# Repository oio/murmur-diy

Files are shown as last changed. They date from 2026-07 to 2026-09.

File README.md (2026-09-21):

# A mur mur's guide to the galaxy

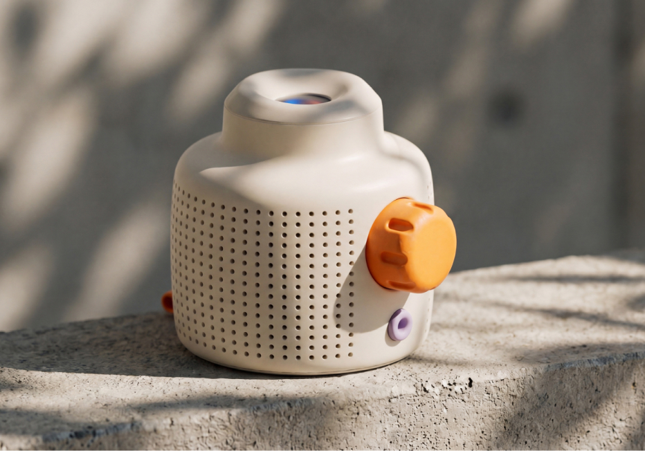
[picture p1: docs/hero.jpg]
mur mur


[mur mur](https://www.murmur.living/) is a small speaker with a world inside.
Not a playlist or a stream, but a living soundscape you can listen to or peek into.

An experiment by [oio](https://oio.studio) and [Mattering](https://matteringstudio.com).

## The DIY version

This guide helps you build the open source hardware prototype of mur mur using readily available off-the-shelf parts. It comes loaded with pre-generated soundscapes for you to enjoy. You can build it with the full feature set (display, battery, charging, and audio) or skip some features for a display-only object. 

Questions while building? Join the oio Discord below:



#### Steps of this guide:

[1 · Order & print parts](#1-order-and-print-parts)

[2 · Upload code](#2-upload-code)

[3 · Assembly](#3-assembly)

[4 · How to use](#4-how-to-use)

## ❶ Order and print parts

First we need to order a bunch of stuff. The complete bill of materials is right below. The diagram shows you where things go. Filaments are sorted by the type of mur mur and print files need to be printed with the different filaments.

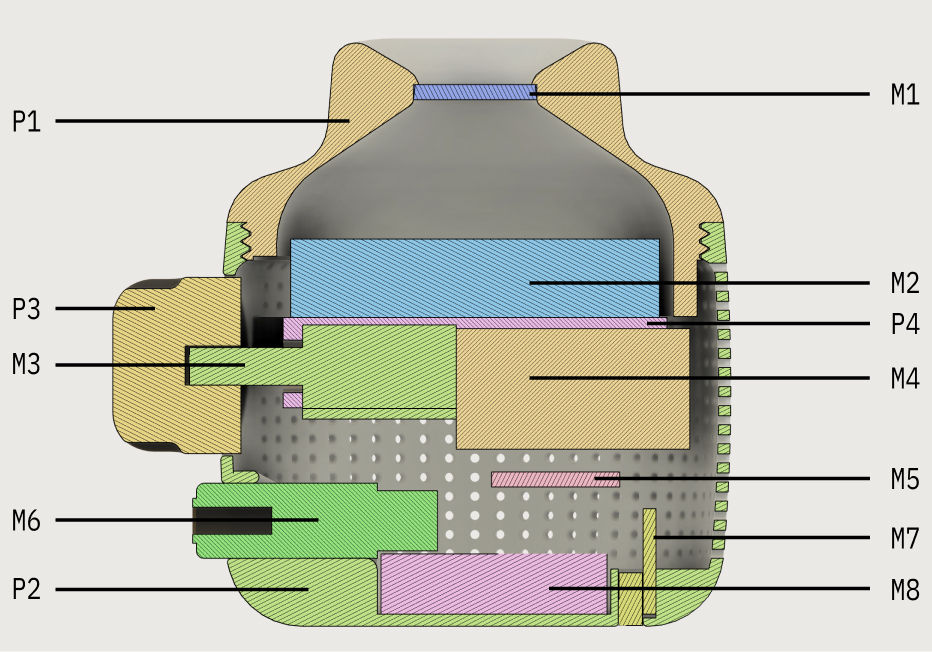
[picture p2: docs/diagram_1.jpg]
BOM diagram


#### BOM

| ID  | Name | Link |
| --- | --- | --- |
| M1  | Lens 16mm (20mm FL) | [Amazon](https://www.amazon.nl/dp/B0G3PH9RPP) |
| M2  | Display Module (ESP32-S3-Touch-AMOLED-1.75, 466×466) | [Waveshare](https://www.waveshare.com/esp32-s3-touch-amoled-1.75.htm) |
| M3  | Amplifier (PAM8403 with potentiometer) | [Amazon](https://www.amazon.nl/dp/B09VT68PHX) |
| M4  | Speaker 3 watt 4 ohm / 2 watt 8 ohm | [Amazon](https://www.amazon.nl/dp/B0DB1WM4QR) |
| M5  | DAC (PCM5102A) | [Amazon](https://www.amazon.nl/dp/B0F7LL4S8Z) |
| M6  | Headphone jack (3.5 mm extension) | [Amazon](https://www.amazon.nl/dp/B0GHQFPSLJ) |
| M7  | Battery charger (TP4057 USB-C) | [Amazon](https://www.amazon.nl/dp/B0F59VQ8JC) |
| M8  | Battery | [Amazon](https://www.amazon.nl/dp/B0F88S2V1Y) |
| M9  | M2 screws | Any 4-6mm M2 bolt |
| M10 | Micro SD | Any MicroSD card (at least 4GB) |
| M11 | Male Pin Header (2.54mm) | Any 2.54mm male header |

> **Note:** Most shopping links point to Amazon Netherlands. The same parts (or close equivalents) are widely available across Europe and the US, use the product names and specs here as a search reference, then order from a local seller if that’s easier.

#### Filament

> **Note:** The filaments listed below are just examples of the exact ones we used for our prototypes. Feel free to use any 3D printing filament (PLA, PETG, etc.) and color combination you like!

| Color | Block | Plot | Pond |
| --- | --- | --- | --- |
| Primary | [Link](https://www.3djake.nl/esun/pla-matte-light-khaki) | [Link](https://www.3djake.nl/esun/pla-matte-matcha-green) | [Link](https://www.3djake.nl/polymaker/polyterra-pla-dual-glacier-blue-ice-blue) |
| Secondary | [Link](https://www.3djake.nl/esun/pla-matte-tangerine) | [Link](https://www.3djake.nl/polymaker/polyterra-pla-dual-camouflage-dark-green-brown) | [Link](https://www.3djake.nl/formfutura/tough-pla-dark-blue?sai=9932) |

#### 3D print files

Print the four parts below before you assemble. Match filament to your mur mur type (Block, Plot, or Pond) from the table above, primary for the shells, secondary for the dial and mount.

| ID  | Name | Color | Link |
| --- | --- | --- | --- |
| P1  | Top shell | Primary | [murmur_top_shell.stl](prints/murmur_top_shell.stl) |
| P2  | Bottom shell | Primary | [murmur_buttom_shell.stl](prints/murmur_buttom_shell.stl) |
| P4  | Mount | Secondary | [murmur_mount.stl](prints/murmur_mount.stl) |

Use supports on the shells (especially overhangs around the openings), and print one part at a time for cleaner surfaces. The mount (P4) holds the display and speaker. Once the parts are printed and the electronics ordered, flash the firmware, then come back here for wiring and assembly.

## ❷ Upload code

Plug in the board via USB-C. One-time setup:

```bash
brew install arduino-cli
arduino-cli core update-index && arduino-cli core install esp32:esp32
arduino-cli lib install JPEGDEC
arduino-cli lib install "GFX Library for Arduino"
```

Flash the firmware:

```bash
cd firmware && ./flash.sh
```

Hold **BOOT** while plugging in USB if the port does not appear. See `[firmware/README.md](firmware/README.md)` for details.

Put your `.avi` files on a FAT32 microSD card (root), insert it, then power on. The video loops on the round 466×466 AMOLED.

> **Battery:** the 1.75 module has onboard AXP2101 charging (MX1.25 battery header). The separate TP4057 charger (M8) is optional if you prefer an external charge board.

## ❸ Assembly

For the assembly you need just a few things:

- 3D printer
- Computer
- Soldering iron
- Wire stripper
- Screwdriver (for M2 screws)
- Double-sided tape

First step is to wire up all the components. Follow the schematic diagram to solder or connect all wires in the right ways. We used male headers and female jumper wires on some parts to make it easier.

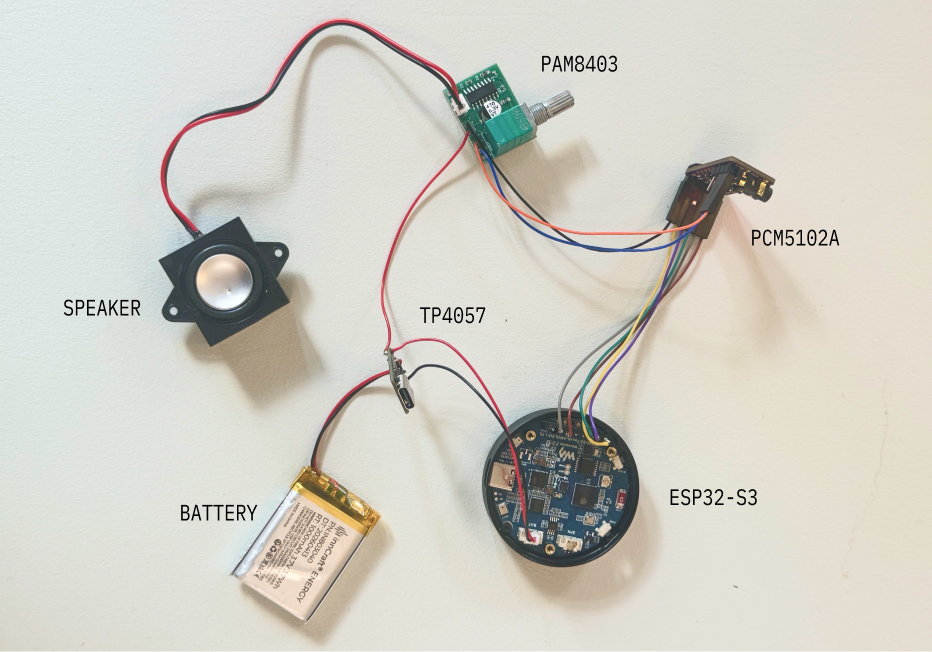
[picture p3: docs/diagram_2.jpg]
Wiring diagram


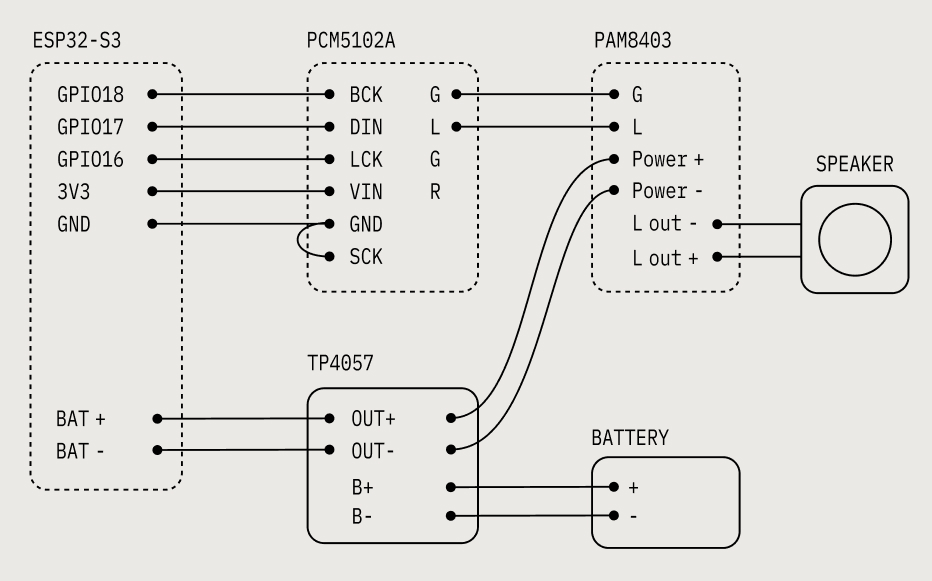
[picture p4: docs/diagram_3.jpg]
Schematic


The diagram above is the pin-level wiring map.

**ESP32-S3 → PCM5102A (I2S):** **GPIO18 → BCK**, **GPIO17 → DIN**, **GPIO16 → LCK**, **3V3 → VIN**, **GND → GND**. Also tie DAC **SCK to GND**.

**PCM5102A → PAM8403 (analog):** **G → G** and **L → L**. Do not swap those two.

**Power:** run **both** PAM8403 **Power +** and **Power −** from the TP4057 (**OUT+** / **OUT−**). Do not take amp power from the ESP 3V3 rail, and do not use the DAC analog ground as the amp’s power ground. The TP4057 also feeds the battery (**B+** / **B−**) and the board’s **BAT +** / **BAT −** connector.

Power the wired stack and confirm video and audio before you close anything up. When that works, put the parts together in the shell.

#### Putting the parts together

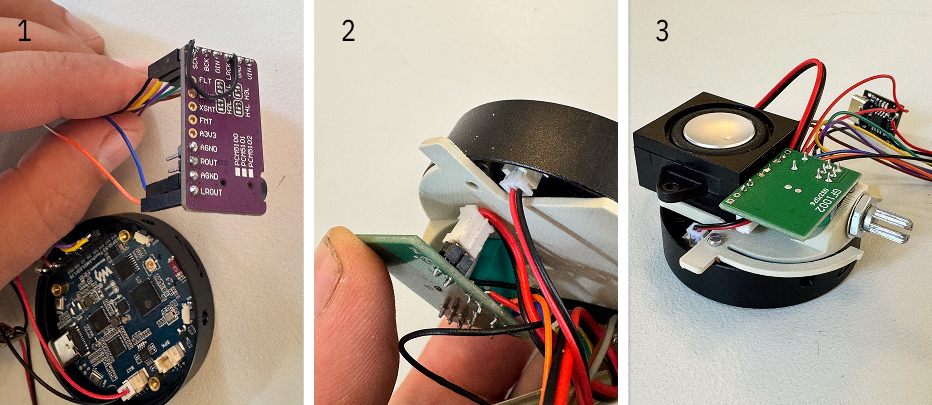
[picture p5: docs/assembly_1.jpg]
Assembly Step 1


1. Add an 8-pin male header to the ESP pinout. Then solder some female jumper cables to GPIO18, 17, 16, 3V3, and GND and connect them to the PCM5102A. Make sure to wire the SCK to GND. See photo as an example.
2. Wire up the audio output from the PCM5102A to the audio input on the PAM8403: **G to G**, **L to L**. Connect PAM8403 **Power +** and **Power −** directly to the TP4057 **OUT+** and **OUT−**.
3. Insert and fasten the PAM8403 to the 3D-printed mounting plate.

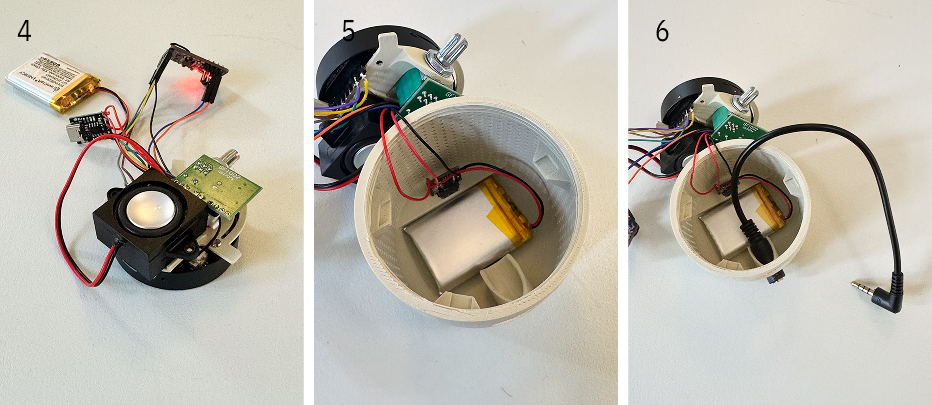
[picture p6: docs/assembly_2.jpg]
Assembly Step 2


4. You should have everything wired up, and it should look something like this. Now is a good time to test the screen and audio. Insert the SD card with the media files and flash the firmware.
5. Insert the battery at the bottom with some double-sided tape, and insert the TP4057 into its dedicated slot.
6. Insert the audio jack cable, doubling as the battery locking system.

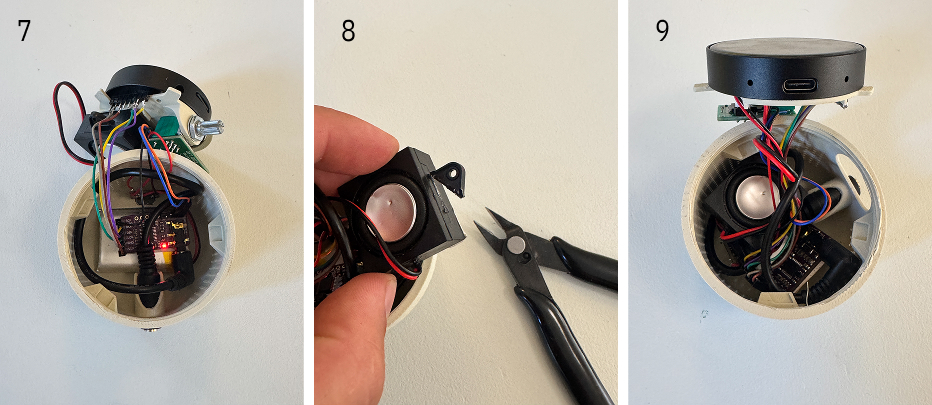
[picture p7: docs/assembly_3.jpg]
Assembly Step 3


7. From here on, we will attempt to fit in all the electronics (this may get tight, depending on the amount of wires and thicknesses). Carefully place the PCM5102A on or next to the battery.
8. It can help to snap off the speaker tabs.
9. Everything should fit inside, leaving clearance above the 3 mounting studs.

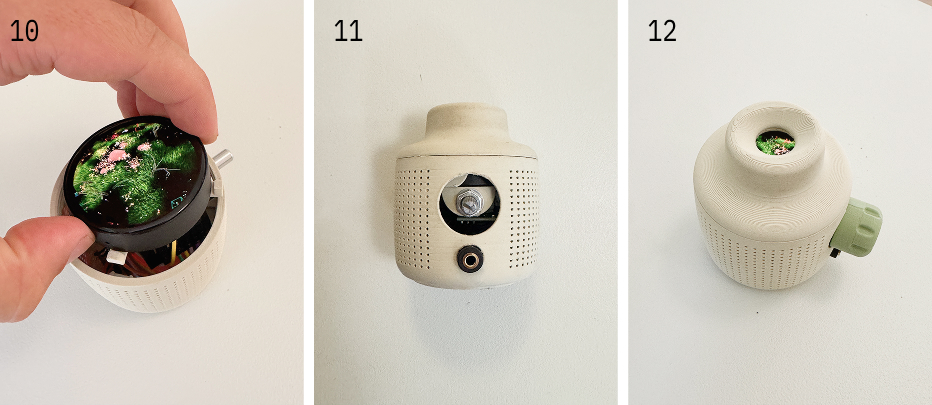
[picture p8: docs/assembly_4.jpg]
Assembly Step 4


10. Insert the display by aligning the mounting pins to the mounting studs.
11. Screw on the top shell with the lens installed. Make sure to rotate the top until the inner opening is revealed (see photo). You may need to clean the 3D-printed edge for a good fit. When fully installed, this will lock the mount and display firmly in place.
12. Plug in the 3D-printed dial, and you should be done. 

## ❹ How to use

Make sure a microSD card with your generated media files (e.g., `city.avi`, `forrest.avi`, `water.avi`) on the root is inserted, then power on. The video loops on the round display with sound through the speaker or headphone jack. Give the device a solid shake to switch between themes!

| Control | Action |
| --- | --- |
| Volume | **Turn** the potentiometer / 3D-printed dial. |
| Shake | **Switch Theme** — changes the current theme (e.g. from city to forest to water). |
| Turn On / Off | **Option 1:** Plug in the charging cable at the bottom.<br>**Option 2:** Insert a needle or wire in the top right 2nd hole.<br>**Option 3:** Unscrew the top shell and click the button manually.|

---

## License

This project is licensed under the [Creative Commons Attribution-NonCommercial-NoDerivatives 4.0 International (CC BY-NC-ND 4.0) License](LICENSE).

---

Stuck on wiring, flashing, or assembly? Hop into the [oio Discord](https://oio.studio/discord) and ask, we are happy to help.



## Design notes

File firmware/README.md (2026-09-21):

# VideoPlayer firmware

Looping MJPEG player for the Waveshare **ESP32-S3-Touch-AMOLED-1.75** (466×466 CO5300 AMOLED).

## Flash from the command line

**Requirements:** USB-C data cable, board plugged in.

**One-time setup:**

```bash
brew install arduino-cli
arduino-cli core update-index
arduino-cli core install esp32:esp32
arduino-cli lib install JPEGDEC
arduino-cli lib install "GFX Library for Arduino"
```

**Flash** (from this folder):

```bash
./flash.sh
```

If the port is not detected, hold **BOOT**, plug in USB, release **BOOT**, then run again.

If several serial ports show up (common on Windows), set the port for one flash:

```bash
PORT=COM3 ./flash.sh
```

Press **RESET** after upload. Insert the SD card (`video.avi` on the root) and connect the speaker.

---

## Hardware Required

| Part | Notes |
|---|---|
| ESP32-S3-Touch-AMOLED-1.75 | Waveshare 466×466 AMOLED module |
| TF / micro-SD card | FAT32, any capacity ≤32 GB |
| Speaker | Plug into the MX1.25 speaker connector |
| USB-C cable | Data-capable (for flashing) |

Battery connects to the onboard MX1.25 lithium header (AXP2101 charging) — no external TP4057 needed.

---

## 1 – Prepare Your Video

```bash
./scripts/convert_for_sd.sh YOUR_INPUT.mp4
```

Or manually:

```bash
ffmpeg -i YOUR_INPUT.mp4 \
  -vf "scale=466:466:force_original_aspect_ratio=decrease,pad=466:466:(ow-iw)/2:(oh-ih)/2,setsar=1" \
  -r 15 \
  -vcodec mjpeg -q:v 8 \
  -af "highpass=f=150,alimiter=limit=-3dB" \
  -acodec pcm_s16le -ar 22050 -ac 1 \
  video.avi
```

Copy `video.avi` to the **root** of the TF card.

---

## Board settings

| Setting | Value |
|---|---|
| Board | `ESP32S3 Dev Module` |
| USB CDC On Boot | `Enabled` |
| Flash Size | `16MB` |
| Partition Scheme | `16M Flash (3MB APP/9.9MB FATFS)` |
| PSRAM | `OPI PSRAM` |
| CPU Frequency | `240MHz` |

---

## Files

```
firmware/
├── firmware.ino             Main sketch
├── AVI_Player.h/.cpp        MJPEG AVI parser + I2S → PCM5102A
├── Display_CO5300.h/.cpp    CO5300 QSPI AMOLED (Arduino_GFX)
├── SD_Card.h/.cpp           TF card (SPI: CLK2/CMD1/D03/CS41)
├── EC11_Volume.h/.cpp       Dial volume + standby
├── TCA9554PWR.h/.cpp        GPIO expander
├── I2C_Driver.h/.cpp        I2C (SDA15 / SCL14)
├── PWR_Key.h/.cpp           Power helpers (AXP2101 button)
└── BAT_Driver.h/.cpp        Battery via AXP2101
```

## Notes

- Audio uses an external **PCM5102A** on GPIO 18/17/16 (BCK/DIN/LCK); tie DAC SCK to GND.
- Volume and standby are controlled by the EC11 dial (TX/RX + EX0).

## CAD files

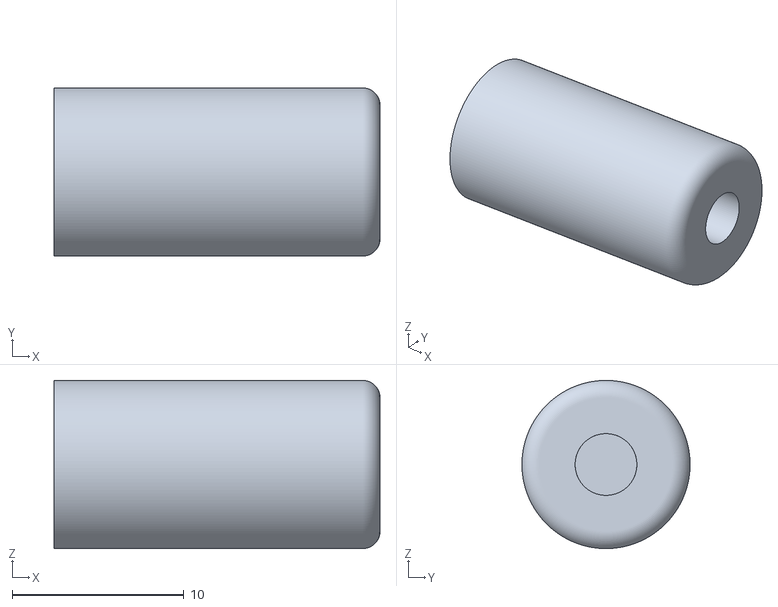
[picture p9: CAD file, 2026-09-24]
prints/murmur_headphone_fake.stl
19.0 x 9.80 x 9.80

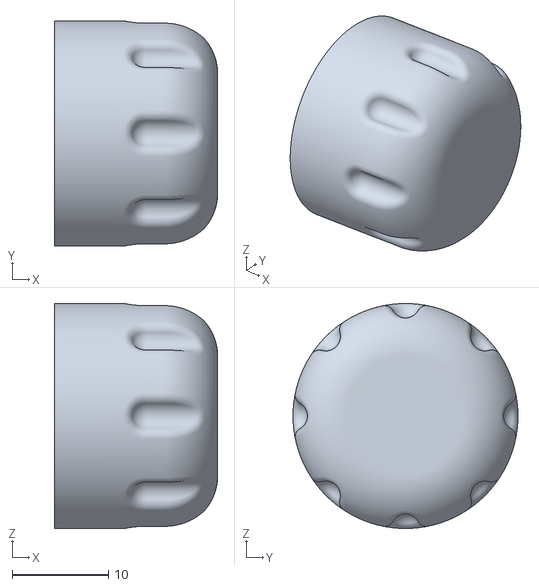
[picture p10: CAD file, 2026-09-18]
prints/murmur_dial.stl
17.0 x 23.4 x 23.4

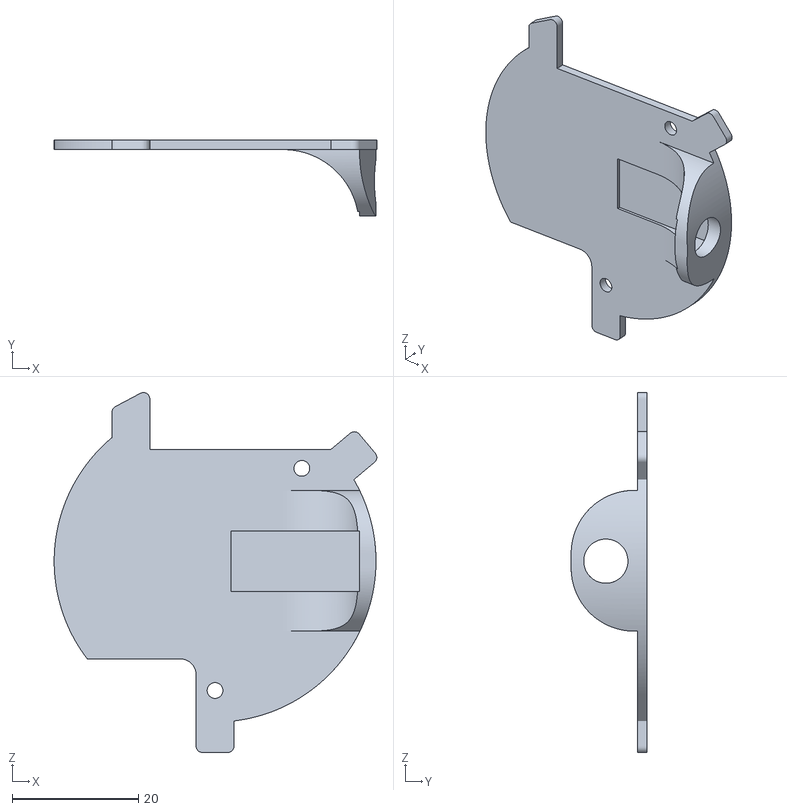
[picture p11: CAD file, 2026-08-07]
prints/murmur_mount.stl
51.1 x 12.0 x 57.0

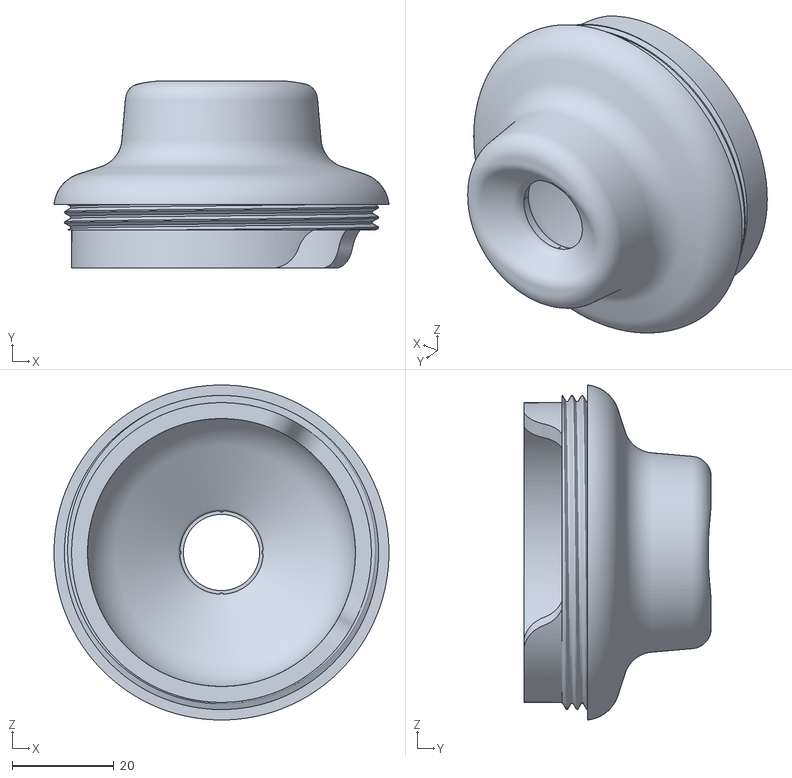
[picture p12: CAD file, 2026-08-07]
prints/murmur_top_shell.stl
65.9 x 36.9 x 65.9

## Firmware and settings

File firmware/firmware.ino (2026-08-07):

/**
 * VideoPlayer.ino – Looping MJPEG video player for Waveshare
 * ESP32-S3-Touch-AMOLED-1.75 (466×466 CO5300).
 *
 * Put your AVI file (named "video.avi") in the root of the TF/SD card.
 * Connect the speaker to the board's MX1.25 speaker connector.
 *
 * See README.md for full setup, video conversion, and flashing instructions.
 *
 * Required libraries (Arduino Library Manager):
 *   JPEGDEC                 by Larry Bank
 *   GFX Library for Arduino by moononournation
 */

#include "Display_CO5300.h"
#include "SD_Card.h"
#include "TCA9554PWR.h"
#include "I2C_Driver.h"
#include "PWR_Key.h"
#include "BAT_Driver.h"
#include "AVI_Player.h"
#include "IMU_Shake.h"
#include "Theme_Manager.h"

static void DriverTask(void *) {
  while (true) {
    PWR_Loop();
    BAT_Get_Volts();
    if (IMU_CheckShake()) {
      Theme_Shake();
    }
    vTaskDelay(pdMS_TO_TICKS(20));
  }
}

void setup() {
  // Use USB CDC for serial, avoid mapping hardware UART to GPIO 1/3 (SD card pins)
  Serial.begin(115200);
  // Serial.setTxTimeoutMs(0);
  delay(200);
  printf("\n=== VideoPlayer boot (466 AMOLED) ===\n");

  PWR_Init();
  I2C_Init(); 
  BAT_Init(); 
  IMU_Init();
  Theme_Init();

  LCD_Init();
  Backlight_Init();
  Set_Backlight(80);

  // Set RXD (GPIO 44) high to output 3.3V
  pinMode(44, OUTPUT);
  digitalWrite(44, HIGH);

  SD_Init();
  AVI_Player_Init();

  xTaskCreatePinnedToCore(DriverTask, "DriverTask", 2048, nullptr, 2, nullptr, 1);

  static uint16_t white_line[EXAMPLE_LCD_WIDTH];
  memset(white_line, 0xFF, sizeof(white_line));
  for (int y = 0; y < EXAMPLE_LCD_HEIGHT; y++)
    LCD_addWindow(0, y, EXAMPLE_LCD_WIDTH - 1, y, white_line);

  float volts = BAT_Get_Volts();
  int pct = (int)((volts - 3.3f) / (4.2f - 3.3f) * 100.0f);
  if (pct < 0)   pct = 0;
  if (pct > 100) pct = 100;
  printf("Battery: %d%%  %.2f V\n", pct, volts);
  
  vTaskDelay(pdMS_TO_TICKS(2000));

  printf("Starting video\n");
}

void loop() {
  const char* nextVid = Theme_GetNextVideo();
  AVI_Player_Play(nextVid);

  if (!Theme_HasChanged()) {
    printf("Video error or finished. Reloading...\n");
  } else {
    Theme_ClearChanged();
    printf("Theme switched! Loading new theme video...\n");
  }

  static uint16_t blk[EXAMPLE_LCD_WIDTH];
  memset(blk, 0, sizeof(blk));
  for (int y = 0; y < EXAMPLE_LCD_HEIGHT; y++)
    LCD_addWindow(0, y, EXAMPLE_LCD_WIDTH - 1, y, blk);

  vTaskDelay(pdMS_TO_TICKS(100)); // small delay before next video starts
}

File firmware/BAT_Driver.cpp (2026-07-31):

#include "BAT_Driver.h"

float BAT_analogVolts = 0;

void BAT_Init(void) {
  // AXP2101 is on the shared I2C bus (initialized by I2C_Init).
}

float BAT_Get_Volts(void) {
  uint8_t hi = 0, lo = 0;
  // I2C_Read returns 0 on success, non-zero on failure (legacy bool API)
  if (I2C_Read(AXP2101_ADDR, AXP2101_REG_VBAT_H, &hi, 1) ||
      I2C_Read(AXP2101_ADDR, AXP2101_REG_VBAT_L, &lo, 1)) {
    BAT_analogVolts = 0;
    return BAT_analogVolts;
  }
  // AXP2101 VBAT is 14-bit, 1 mV/LSB
  const uint16_t raw = ((uint16_t)(hi & 0x3F) << 8) | lo;
  BAT_analogVolts = raw / 1000.0f;
  return BAT_analogVolts;
}

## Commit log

2026-07-31 Clean DIY repo
    [murmur_dial.stl, murmur_mount.stl, murmur_top_shell.stl]
2026-07-31 assembly images
2026-09-18 dial tolerances
    [murmur_dial.stl]
2026-09-21 Fix wiring schematic and flash port auto-detect
    Correct PCM5102A→PAM8403 wiring (G/L, TP4057 power) and diagram.
    flash.sh finds COM ports on Windows; use PORT= if ambiguous.
    Thanks Discord builders for the catches.
2026-09-24 Headphone jack STL
    A fake option to replace the headphone jack extension.
    [murmur_headphone_fake.stl]
